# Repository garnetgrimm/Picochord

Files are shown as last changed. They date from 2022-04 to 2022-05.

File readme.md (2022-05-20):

# Picochord
An open source digital Omnichord clone based on the Raspberry Pi Pico. The firmware is currently configured to only generate audio from the input signals, but usb/analog midi support is in the works for the near future.
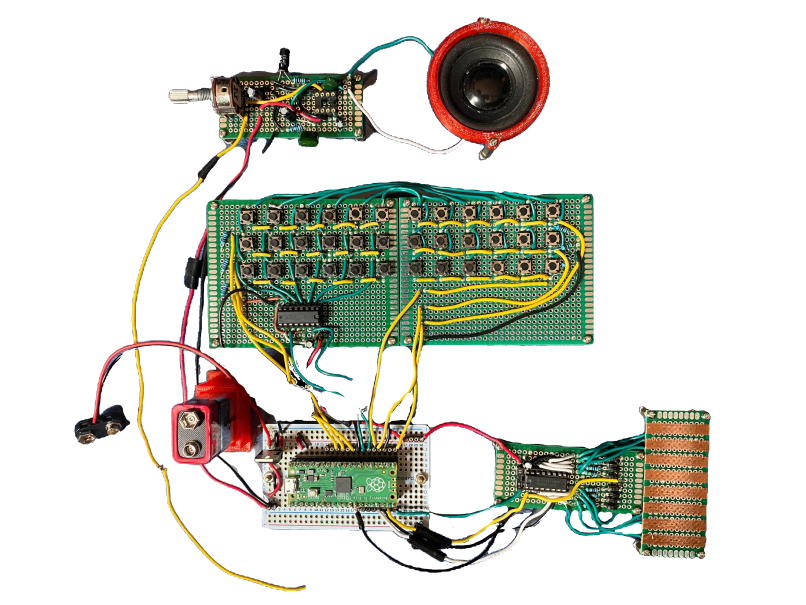
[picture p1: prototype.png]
Prototype


## Building the Firmware
The getting started guide has detailed instructions for building on each OS. https://datasheets.raspberrypi.com/pico/getting-started-with-pico.pdf

You will likely have to cd into the build directory to configure cmake and build.

## Circuits
The entire Picochord is comprised of three main subcircuits, all driven by the pico. 

* Keypad
* Strumpad
* Speaker amplifier

The PCB directory contains simulations, schematics, PCB's and screenshots for each of the circuits. The schematics/PCBs can be viewed with KiCad 6.0

## Chassis
The PCB's were screwed directly into a acrylic board. The only other required pieces were a battery holder and speaker holder which I have included STL's and FreeCad files for.

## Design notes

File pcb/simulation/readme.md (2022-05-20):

# Simulations
To view a live demo of the circuits follow these steps

* Go to https://www.falstad.com/circuit/circuitjs.html
* "Open File"
* Upload either of the .circuitjs.txt files

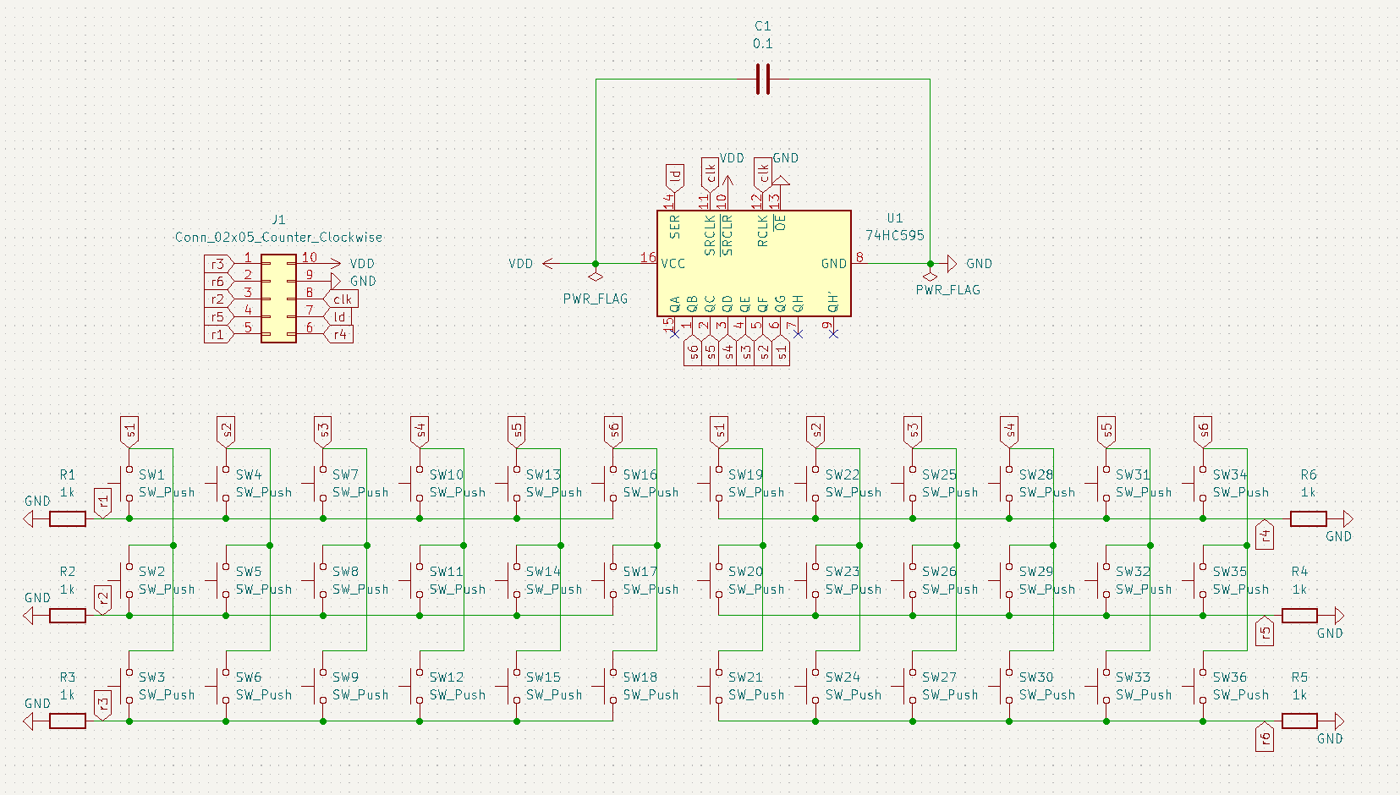
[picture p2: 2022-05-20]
pcb/image/keypad_schematic.png

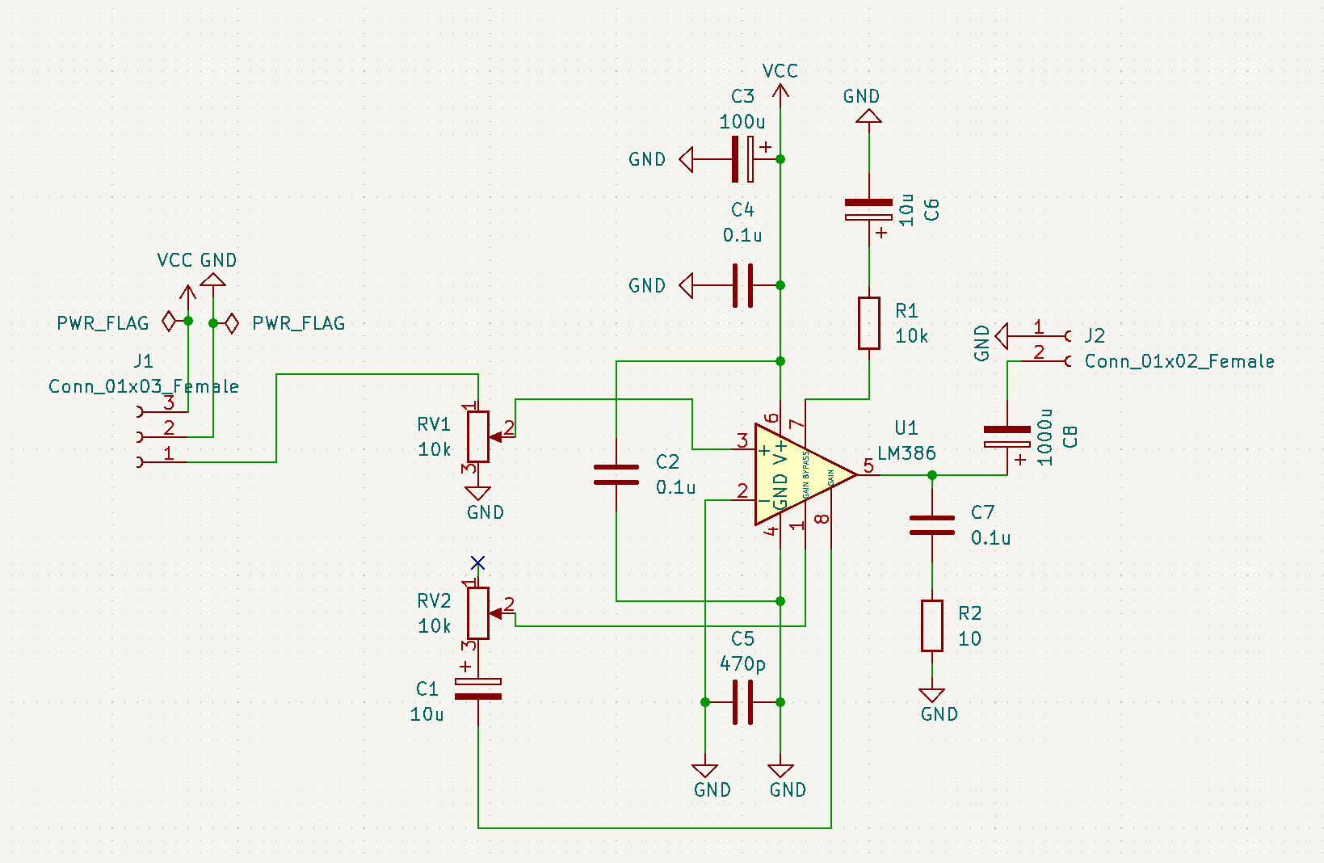
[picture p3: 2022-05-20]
pcb/image/speaker_schematic.png

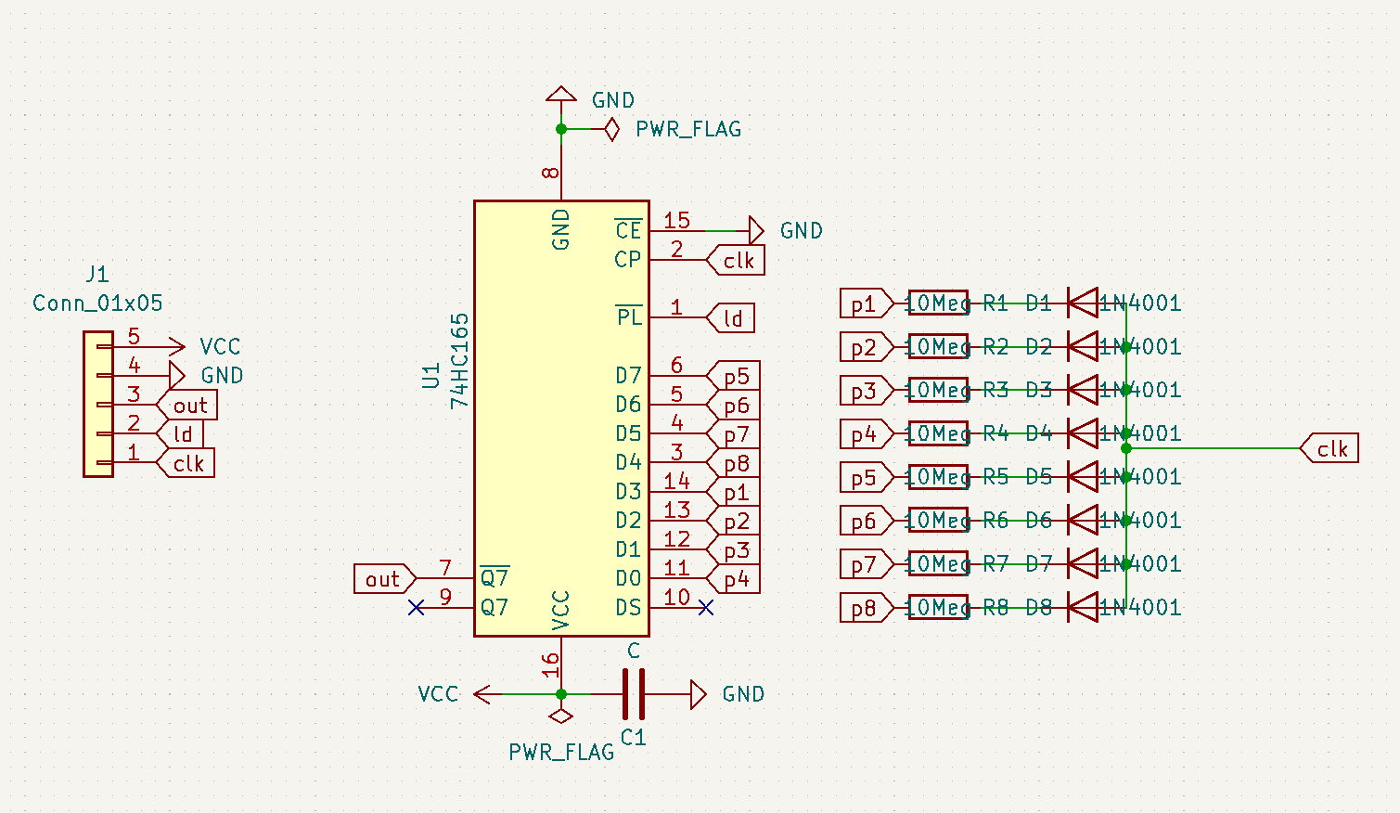
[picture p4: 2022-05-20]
pcb/image/strumpad_schematic.png

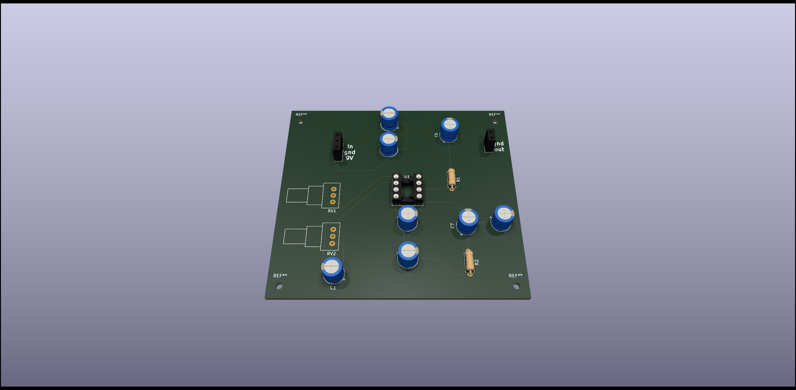
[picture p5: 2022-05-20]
pcb/image/speaker.png

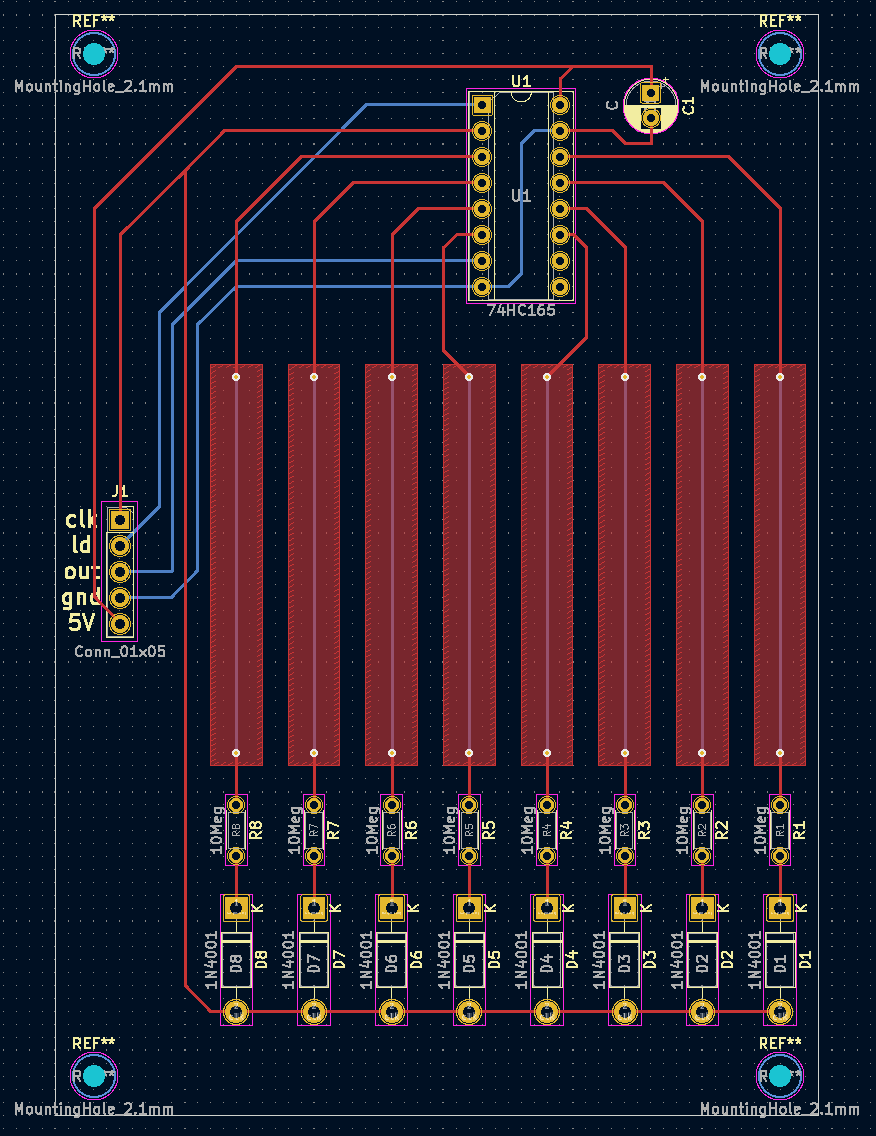
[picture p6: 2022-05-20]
pcb/image/strumpad_pcb.png

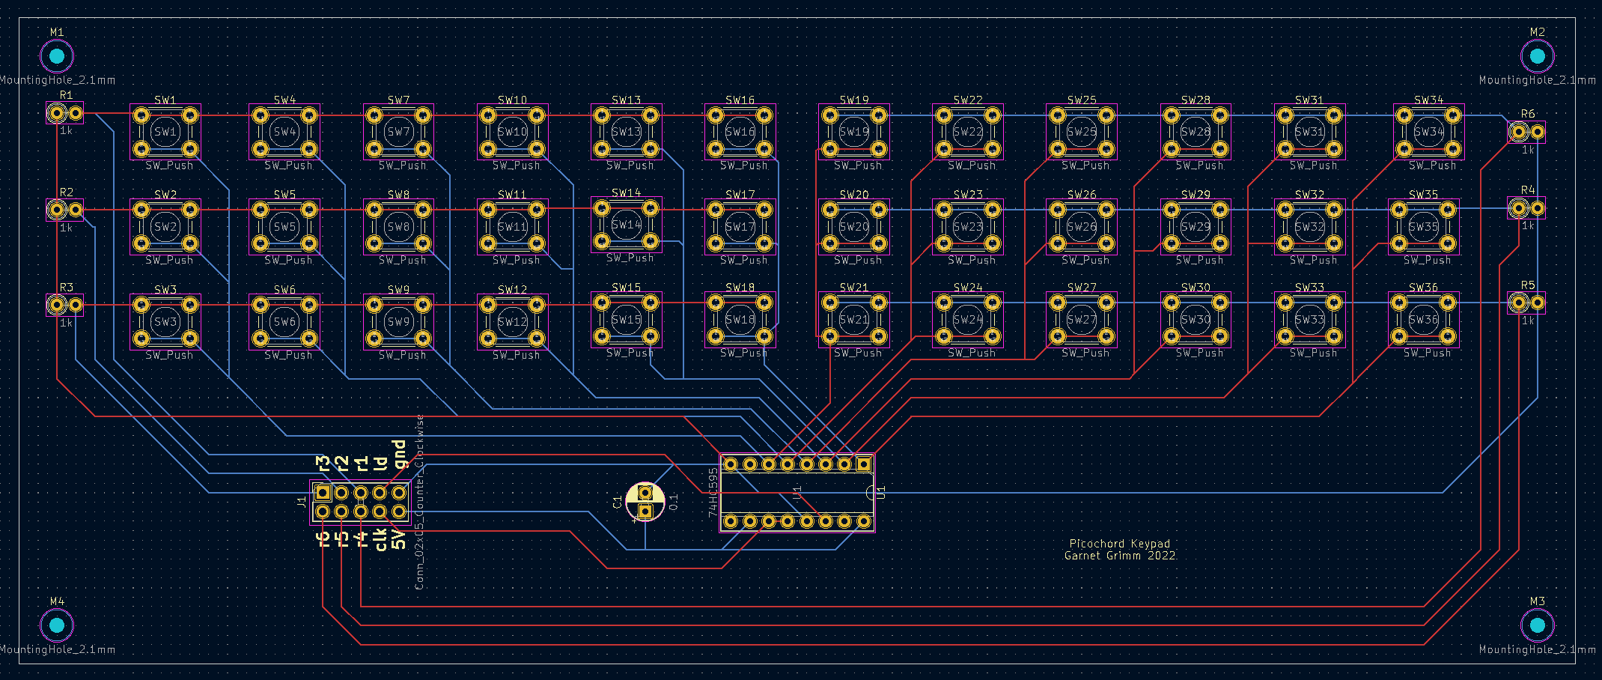
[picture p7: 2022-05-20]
pcb/image/keypad_pcb.png

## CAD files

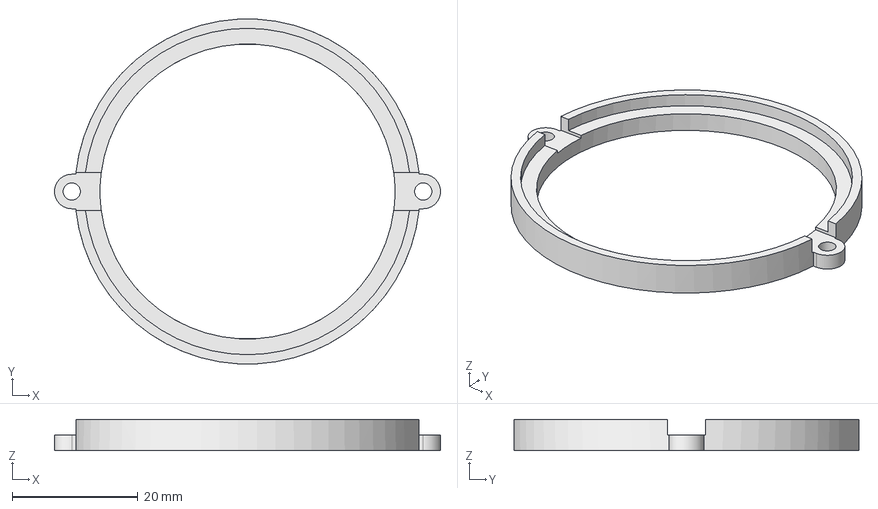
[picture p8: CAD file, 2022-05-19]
chassis/speaker_support.FCStd
61.5 x 54.9 x 5.00 mm

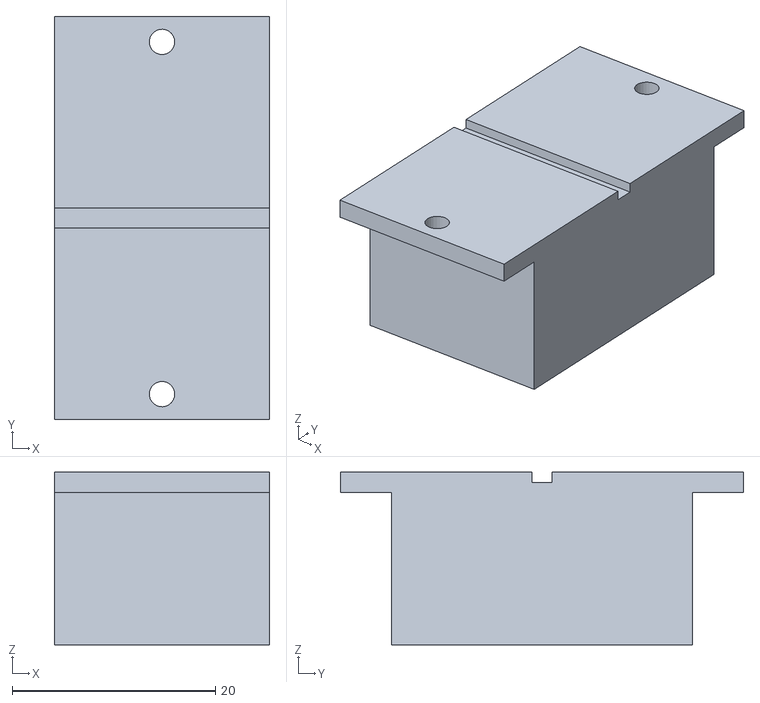
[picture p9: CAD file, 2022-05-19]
chassis/battery_support.stl
21.2 x 39.7 x 17.0

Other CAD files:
chassis/speaker_support.stl

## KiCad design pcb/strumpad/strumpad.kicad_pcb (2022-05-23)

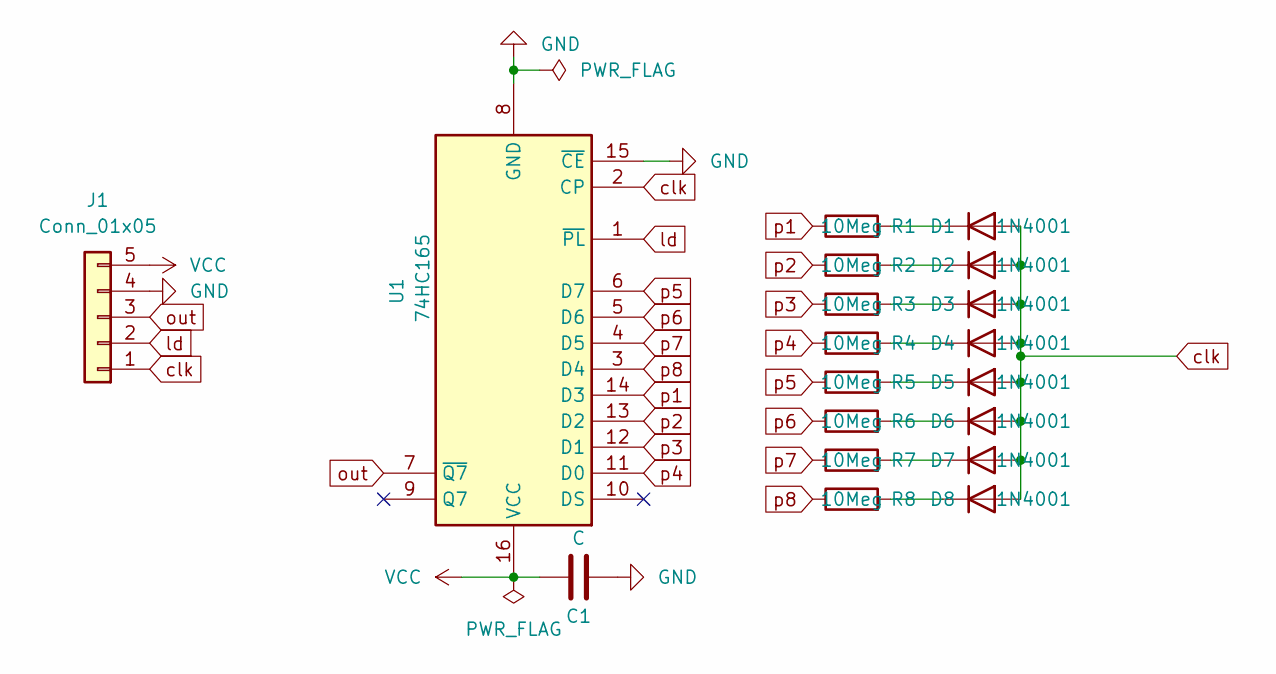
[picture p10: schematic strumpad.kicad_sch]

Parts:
C1: C; CP_Radial_D5.0mm_P2.50mm
D1, D2, D3, D4, D5, D6, D7, D8: 1N4001; D_DO-41_SOD81_P10.16mm_Horizontal
J1: Conn_01x05; PinSocket_1x05_P2.54mm_Vertical
R1, R2, R3, R4, R5, R6, R7, R8: 10Meg; R_Axial_DIN0204_L3.6mm_D1.6mm_P5.08mm_Horizontal
U1: 74HC165; DIP-16_W7.62mm_Socket

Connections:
GND: C1.2, J1.4, U1.8 (GND), U1.15 (~CE)
unnamed: D1.1 (K), R1.2
unnamed: D2.1 (K), R2.2
unnamed: D3.1 (K), R3.2
unnamed: D4.1 (K), R4.2
unnamed: D5.1 (K), R5.2
unnamed: D6.1 (K), R6.2
unnamed: D7.1 (K), R7.2
unnamed: D8.1 (K), R8.2
VCC: C1.1, J1.5, U1.16 (VCC)
clk: D1.2 (A), D2.2 (A), D3.2 (A), D4.2 (A), D5.2 (A), D6.2 (A), D7.2 (A), D8.2 (A), J1.1, U1.2 (CP)
ld: J1.2, U1.1 (~PL)
out: J1.3, U1.7 (~Q7)
p1: R1.1, U1.14 (D3)
p2: R2.1, U1.13 (D2)
p3: R3.1, U1.12 (D1)
p4: R4.1, U1.11 (D0)
p5: R5.1, U1.6 (D7)
p6: R6.1, U1.5 (D6)
p7: R7.1, U1.4 (D5)
p8: R8.1, U1.3 (D4)

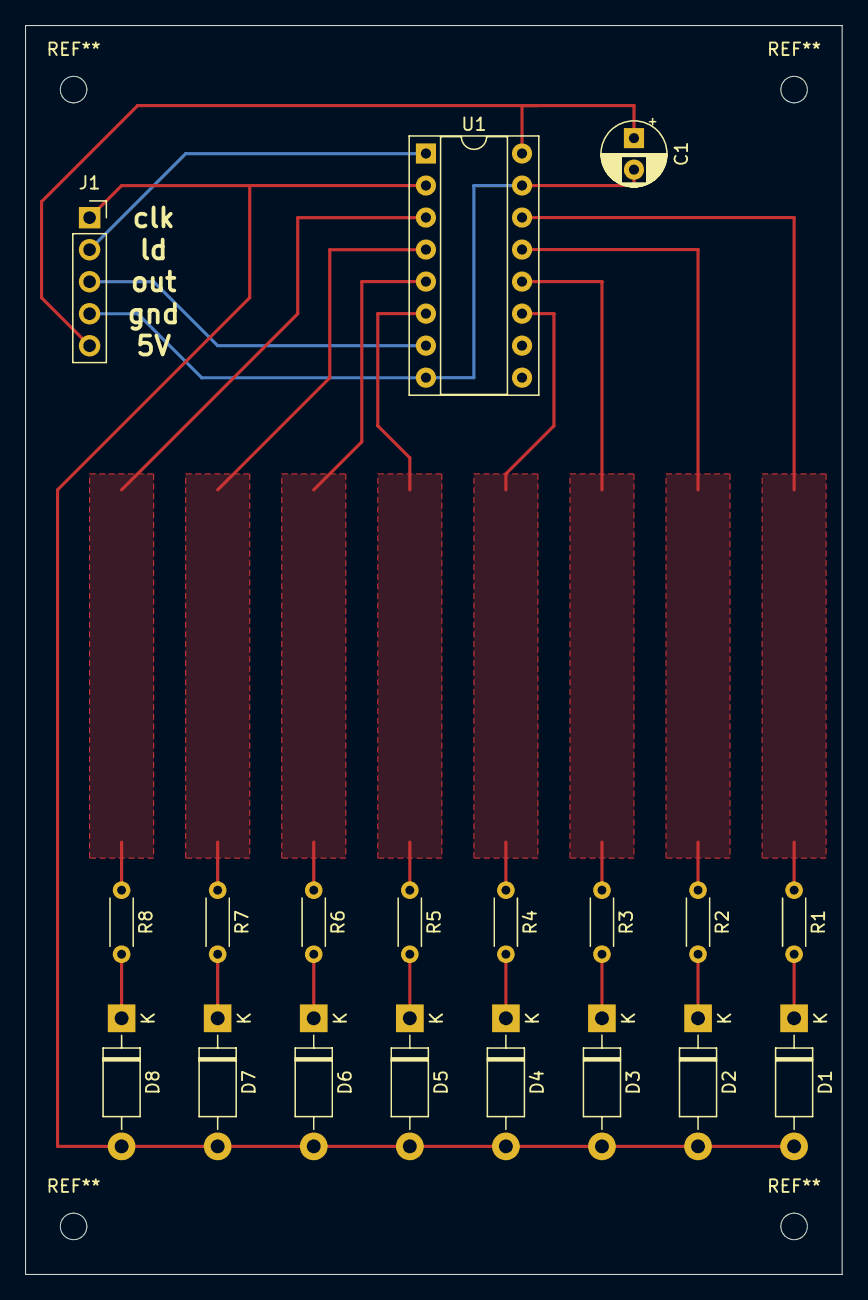
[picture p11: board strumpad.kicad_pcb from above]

Board: 2 copper layers, 64.8 x 99.1 mm, 19 parts (0 on the bottom side), 21 nets.

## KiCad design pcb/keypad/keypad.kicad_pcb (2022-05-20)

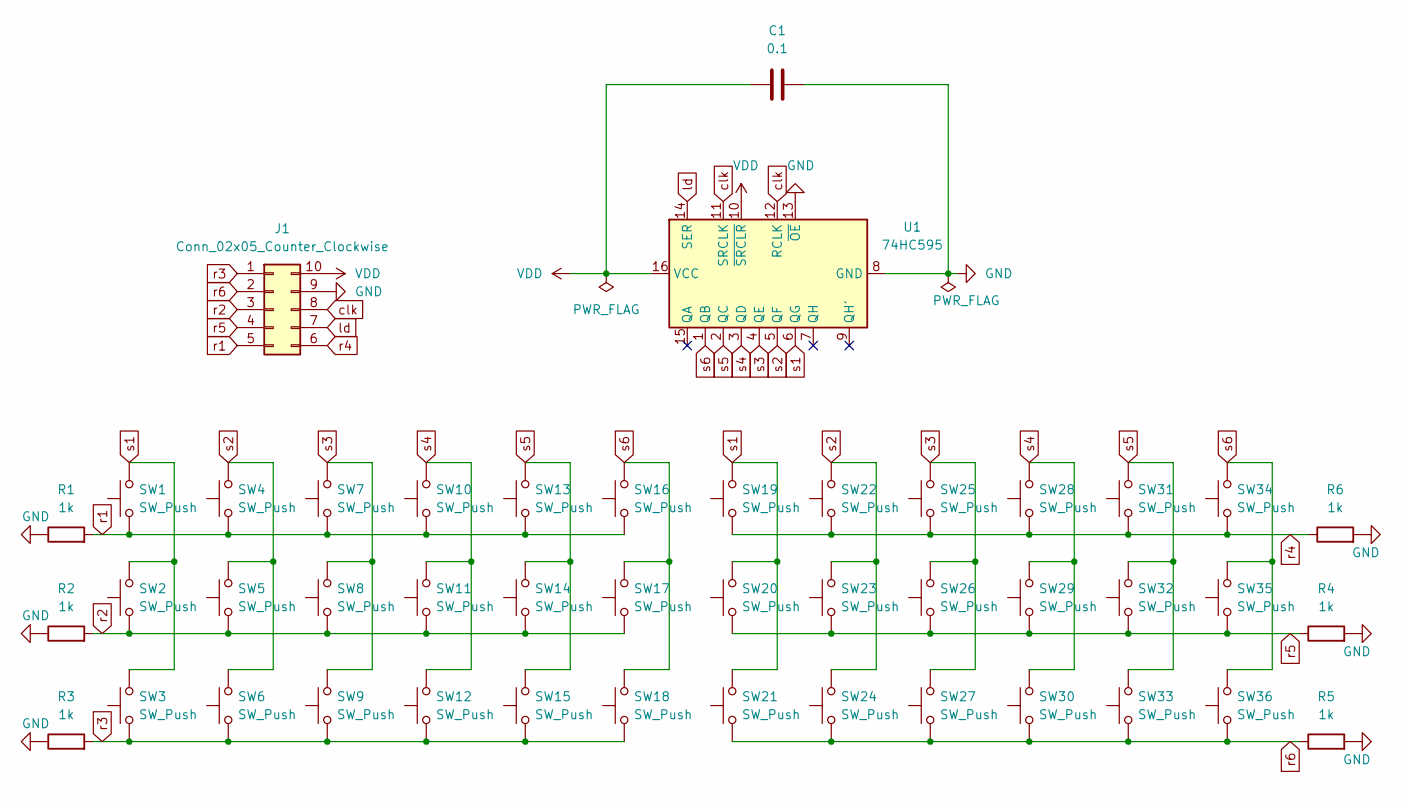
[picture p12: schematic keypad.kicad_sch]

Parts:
C1: 0.1; CP_Radial_D5.0mm_P2.50mm
J1: Conn_02x05_Counter_Clockwise; PinSocket_2x05_P2.54mm_Vertical
R1, R2, R3, R4, R5, R6: 1k; R_Axial_DIN0207_L6.3mm_D2.5mm_P2.54mm_Vertical
SW1, SW2, SW3, SW4, SW5, SW6, SW7, SW8, SW9, SW10, SW11, SW12, SW13, SW14, SW15, SW16, SW17, SW18, SW19, SW20, SW21, SW22, SW23, SW24, SW25, SW26, SW27, SW28, SW29, SW30, SW31, SW32, SW33, SW34, SW35, SW36: SW_Push; SW_PUSH_6mm
U1: 74HC595; DIP-16_W7.62mm_Socket

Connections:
GND: C1.2, J1.9, R1.1, R2.1, R3.1, R4.2, R5.2, R6.2, U1.8 (GND), U1.13 (~OE)
VDD: C1.1, J1.10, U1.10 (~SRCLR), U1.16 (VCC)
clk: J1.8, U1.11 (SRCLK), U1.12 (RCLK)
ld: J1.7, U1.14 (SER)
r1: J1.5, R1.2, SW1.1, SW4.1, SW7.1, SW10.1, SW13.1, SW16.1
r2: J1.3, R2.2, SW2.1, SW5.1, SW8.1, SW11.1, SW14.1, SW17.1
r3: J1.1, R3.2, SW3.1, SW6.1, SW9.1, SW12.1, SW15.1, SW18.1
r4: J1.6, R6.1, SW19.1, SW22.1, SW25.1, SW28.1, SW31.1, SW34.1
r5: J1.4, R4.1, SW20.1, SW23.1, SW26.1, SW29.1, SW32.1, SW35.1
r6: J1.2, R5.1, SW21.1, SW24.1, SW27.1, SW30.1, SW33.1, SW36.1
s1: SW1.2, SW2.2, SW3.2, SW19.2, SW20.2, SW21.2, U1.6 (QG)
s2: SW4.2, SW5.2, SW6.2, SW22.2, SW23.2, SW24.2, U1.5 (QF)
s3: SW7.2, SW8.2, SW9.2, SW25.2, SW26.2, SW27.2, U1.4 (QE)
s4: SW10.2, SW11.2, SW12.2, SW28.2, SW29.2, SW30.2, U1.3 (QD)
s5: SW13.2, SW14.2, SW15.2, SW31.2, SW32.2, SW33.2, U1.2 (QC)
s6: SW16.2, SW17.2, SW18.2, SW34.2, SW35.2, SW36.2, U1.1 (QB)

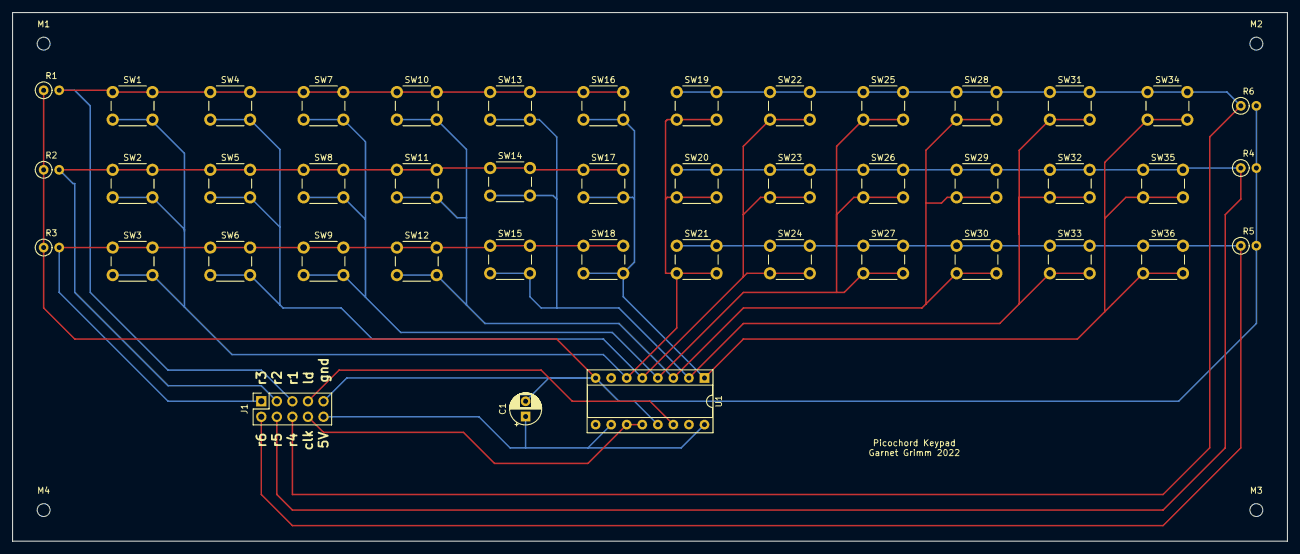
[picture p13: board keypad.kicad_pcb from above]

Board: 2 copper layers, 208.3 x 86.4 mm, 49 parts (0 on the bottom side), 16 nets.

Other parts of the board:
M1, M2, M3, M4: MountingHole_2.1mm

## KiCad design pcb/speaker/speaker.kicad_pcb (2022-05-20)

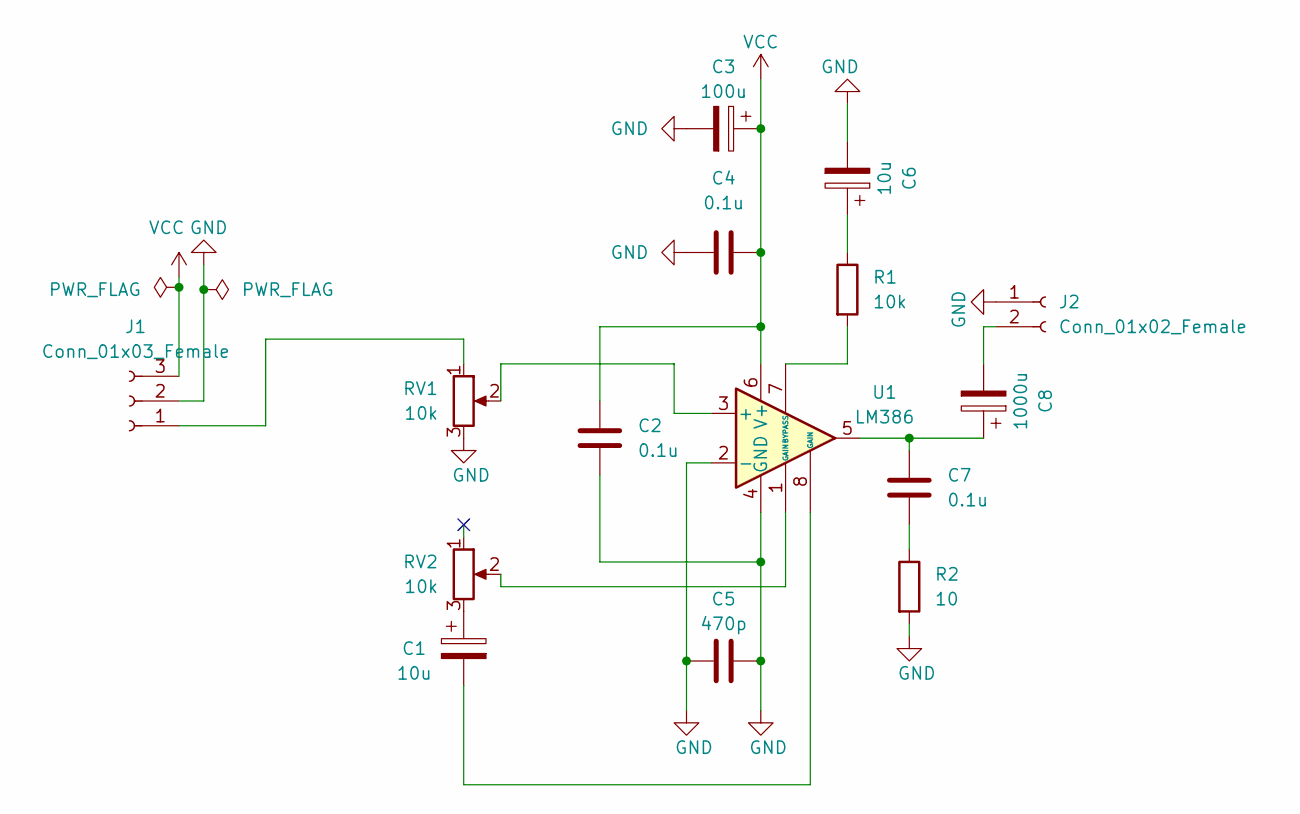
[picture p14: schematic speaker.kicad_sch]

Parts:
C1, C6: 10u; CP_Radial_D6.3mm_P2.50mm
C2, C4, C7: 0.1u; CP_Radial_D6.3mm_P2.50mm
C3: 100u; CP_Radial_D6.3mm_P2.50mm
C5: 470p; CP_Radial_D6.3mm_P2.50mm
C8: 1000u; CP_Radial_D6.3mm_P2.50mm
J1: Conn_01x03_Female; PinSocket_1x03_P2.54mm_Vertical
J2: Conn_01x02_Female; PinSocket_1x02_P2.54mm_Vertical
R1: 10k; R_Axial_DIN0207_L6.3mm_D2.5mm_P7.62mm_Horizontal
R2: 10; R_Axial_DIN0207_L6.3mm_D2.5mm_P7.62mm_Horizontal
RV1, RV2: 10k; Potentiometer_Alps_RK09Y11_Single_Horizontal
U1: LM386; DIP-8_W7.62mm_Socket

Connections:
GND: C2.1, C3.2, C4.1, C5.1, C5.2, C6.2, J1.2, J2.1, R2.2, RV1.3, U1.2 (-), U1.4 (GND)
unnamed: C1.1, RV2.3
unnamed: C1.2, U1.8 (GAIN)
unnamed: C6.1, R1.1
unnamed: C7.1, R2.1
unnamed: C7.2, C8.1, U1.5
unnamed: C8.2, J2.2
unnamed: R1.2, U1.7 (BYPASS)
unnamed: J1.1, RV1.1
unnamed: RV1.2, U1.3 (+)
unnamed: RV2.2, U1.1 (GAIN)
VCC: C2.2, C3.1, C4.2, J1.3, U1.6 (V+)

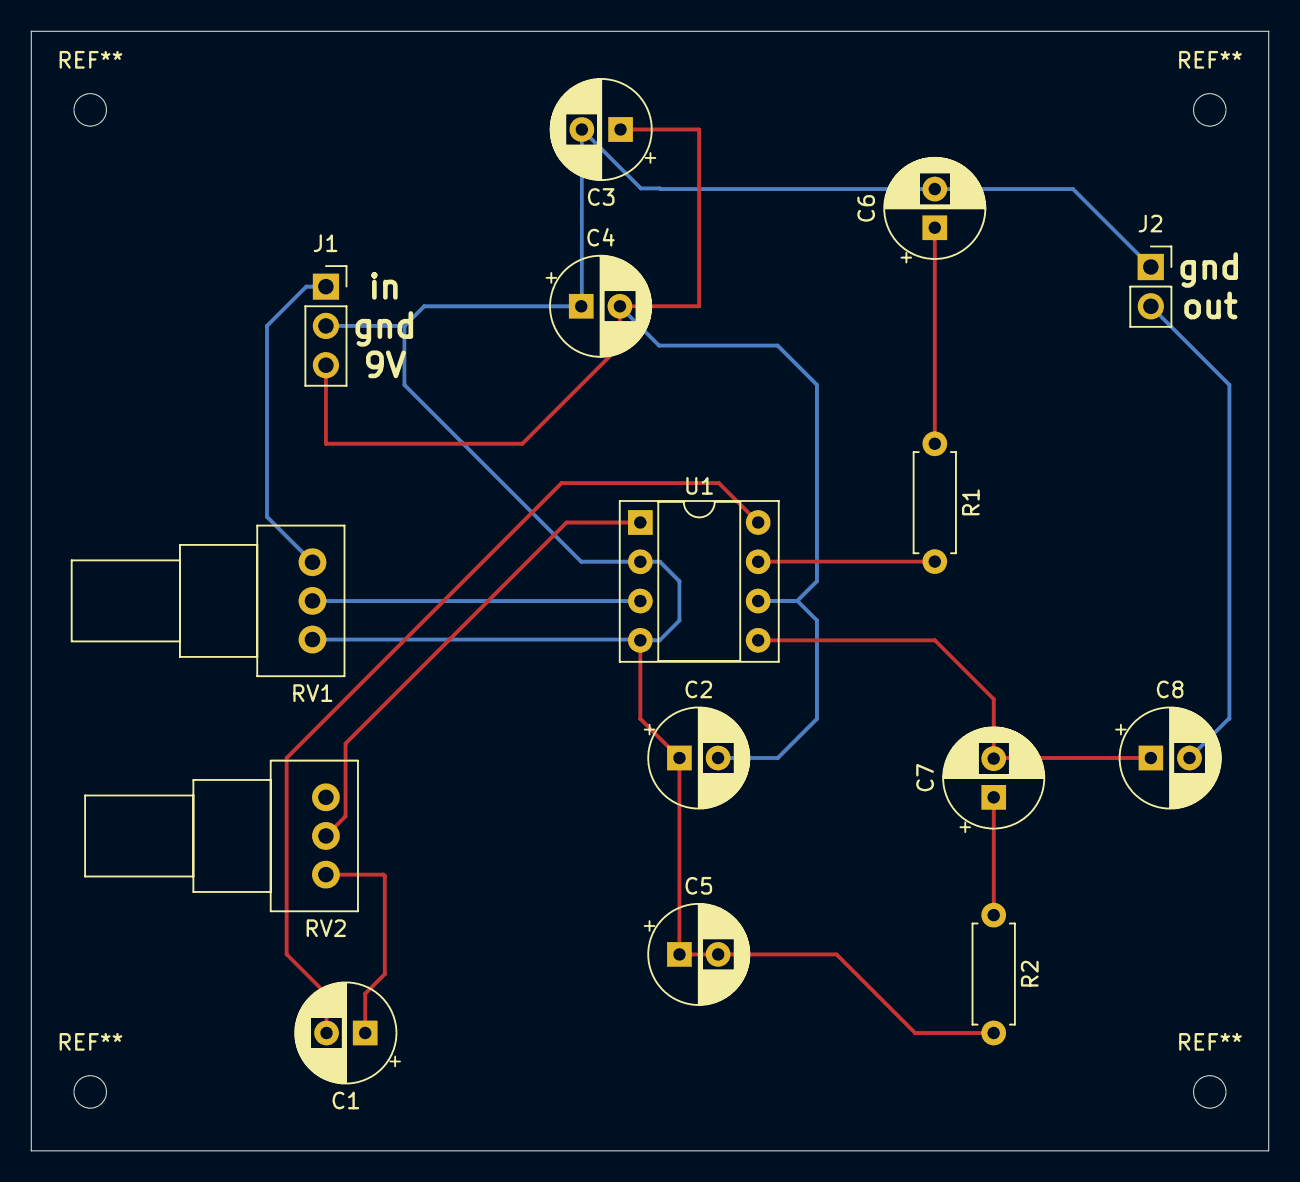
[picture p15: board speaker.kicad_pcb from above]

Board: 2 copper layers, 80.0 x 72.4 mm, 15 parts (0 on the bottom side), 12 nets.

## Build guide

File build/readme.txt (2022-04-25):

Steps to build

Developer Command Prompt for VS
cd build
cmake -G "NMake Makefiles" ..
nmake

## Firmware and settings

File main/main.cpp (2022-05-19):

#include <stdio.h>
#include <math.h>
#include "pico/stdlib.h"
#include "hardware/gpio.h"
#include "hardware/clocks.h"
#include "hardware/pwm.h"
#include "hardware/adc.h"
#include "hardware/irq.h"  // interrupts
#include "hardware/sync.h" // wait for interrupt 
 
// Audio PIN is to match some of the design guide shields. 
#define OSCILLATORS 16

#include "chord.h"
#include "keypad.h"
#include "oscillator.h"
#include "strumpad.h"

const uint8_t audioPin = 10;
const uint8_t sLOADPin = 15;  //strumpad load pin
const uint8_t sCLKPin = 14;	 //strumpad clock pin
const uint8_t sINPin = 13;	 //strumpad input pin
//use some of the previously skipped pins. They're ok to use, the associated timer is just being utilized.
const uint8_t kLOADPin = 20; //keypad load pin
const uint8_t kCLKPin = 21;	 //keypad clock pin
const uint8_t kR1Pin = 27;	 //keypad row one pin
const uint8_t kR2Pin = 26;	 //keypad row two pin
const uint8_t kR3Pin = 22;	 //keypad row three pin
const uint8_t kR4Pin = 16;	 //keypad row one pin
const uint8_t kR5Pin = 18;	 //keypad row two pin
const uint8_t kR6Pin = 19;	 //keypad row three pin

uint8_t current_col = 0;
uint8_t current_pad = 0;

const float keypadLoadHz = 60.0f;
const float keypadClockHz = keypadClockHz * (float)cols;
const float strumLoadHz = 500.0f;

SquareWave wave;
Oscillator oscs[OSCILLATORS];

Chord chord = NoChord();

Keypad activePad;
Keypad finalPad;

Strumpad strumPad;

uint8_t level = 0;

bool mute_chord = true;

uint32_t strum_load_cnt = 0;
uint32_t strum_load_max = 15;
uint32_t strum_tick_time = 250;

bool blinky = false;

float midiFreq(int midiNum) {
	return 440.0f*powf(2.0f, ((float)midiNum - 69.0f) / 12.0f);
}

void pwm_interrupt_handler() {
    pwm_clear_irq(pwm_gpio_to_slice_num(audioPin));
    pwm_set_gpio_level(audioPin, level);
}

bool tick_oscillators(struct repeating_timer *t) {
	sink sum { 0.0f };
	if(!mute_chord) {
		for(int i = 0; i < 3; i++) {	
			sum += oscs[i].tick(false);
		}
	}
	for(int i = 3; i < 11; i++) {	
		sum += oscs[i].tick(true);
	}
	level = static_cast<int8_t>((20)*sum) + 0x7F;
	return true;
}

void set_chord(Chord c) {
	chord = c;
	if(chord.type == BLANK) {
		mute_chord = true;
		for(int i = 0; i < 3; i++) {
			oscs[i].set_freq(440);
		}
	} else {
		mute_chord = false;
		for(int i = 0; i < 3; i++) {
			float freq = midiFreq(chord[i % 3]);
			oscs[i].set_freq(freq);
		}
		for(int i = 3; i < OSCILLATORS; i++) {
			float freq = midiFreq(chord[i % 3]);
			int fscale = 1<<((i-3)/3);
			oscs[i].set_freq(freq*(float)fscale);
		}
	}
}

void tick_strumpad(void) {
	if(strum_load_cnt == 10) {
		gpio_put(sLOADPin, false);
		gpio_put(sCLKPin, false);
		gpio_put(sLOADPin, true);
	}
	
	if(strum_load_cnt < strum_load_max)  {
		strum_load_cnt++;
		return;
	}
	
	if(!gpio_get_out_level(sCLKPin)) {
		
		bool pad_on = gpio_get(sINPin) && (current_pad == 7);
		strumPad.set_strumpad(current_pad, pad_on);
		if(pad_on) {
			oscs[current_pad + 3].volume = sink(1.0f);
		}
		
		current_pad++;
		if(current_pad > 8) {
			current_pad = 0;
			gpio_put(sCLKPin, true);
			strum_load_cnt = 0;
			return;
		} else {
			gpio_put(sCLKPin, true);
		}
	} else {
		gpio_put(sCLKPin, false);
	}
}

void tick_keypad(void) {
	bool clkStat = gpio_get_out_level(kCLKPin);	
	
	if(clkStat) {
		activePad.set_keypad(0, 5 - (current_col - 2), gpio_get(kR1Pin));
		activePad.set_keypad(1, 5 - (current_col - 2), gpio_get(kR2Pin));
		activePad.set_keypad(2, 5 - (current_col - 2), gpio_get(kR3Pin));
		activePad.set_keypad(0, current_col - 2 + 6, gpio_get(kR4Pin));
		activePad.set_keypad(1, current_col - 2 + 6, gpio_get(kR5Pin));
		activePad.set_keypad(2, current_col - 2 + 6, gpio_get(kR6Pin));
		current_col++;
		
		gpio_put(kLOADPin, false);
	}
	
	gpio_put(kCLKPin, !clkStat);
	
	if(current_col >= cols) {
		current_col = 0;
		gpio_put(kLOADPin, true);
		
		finalPad.update(activePad);	
		
		Chord detChord = finalPad.to_chord();		
		if(detChord.type != chord.type || detChord.root != chord.root) {
			set_chord(detChord);
		};
	}
}

bool input_ISR(struct repeating_timer *t) {
	tick_keypad();
	tick_strumpad();
	return true;
}

int main(void) {
	
    stdio_init_all();
	set_chord(MajChord(noteMap[0]));
	
	const uint LED_PIN = PICO_DEFAULT_LED_PIN;
    gpio_init(LED_PIN);
    gpio_set_dir(LED_PIN, GPIO_OUT);
	
	//strumpad control signals
	gpio_init(sLOADPin);
	gpio_init(sCLKPin);
	gpio_init(sINPin);

	gpio_set_dir(sLOADPin, GPIO_OUT);
	gpio_set_dir(sCLKPin, GPIO_OUT);
	gpio_set_dir(sINPin, GPIO_IN);
	
	//keypad control signals
	gpio_init(kLOADPin);
	gpio_init(kCLKPin);
	gpio_init(kR1Pin);
	gpio_init(kR2Pin);
	gpio_init(kR3Pin);
	gpio_init(kR4Pin);
	gpio_init(kR5Pin);
	gpio_init(kR6Pin);
	
    gpio_set_dir(kLOADPin, GPIO_OUT);
	gpio_set_dir(kCLKPin,  GPIO_OUT);
	gpio_set_dir(kR1Pin,   GPIO_IN);
	gpio_set_dir(kR2Pin,   GPIO_IN);
	gpio_set_dir(kR3Pin,   GPIO_IN);	
	gpio_set_dir(kR4Pin,   GPIO_IN);
	gpio_set_dir(kR5Pin,   GPIO_IN);
	gpio_set_dir(kR6Pin,   GPIO_IN);	

    set_sys_clock_khz(176000, true); 
    gpio_set_function(audioPin, GPIO_FUNC_PWM);

    int audio_pin_slice = pwm_gpio_to_slice_num(audioPin);

    // Setup PWM interrupt to fire when PWM cycle is complete
    pwm_clear_irq(audio_pin_slice);
    pwm_set_irq_enabled(audio_pin_slice, true);
    // set the handle function above
    irq_set_exclusive_handler(PWM_IRQ_WRAP, pwm_interrupt_handler); 
    irq_set_enabled(PWM_IRQ_WRAP, true);

    // Setup PWM for audio output
    pwm_config config = pwm_get_default_config();
    //Base clock 176,000,000 Hz divide by wrap 250 then the clock divider further divides
    //to set the interrupt rate. 
    //11 KHz is fine for speech. Phone lines generally sample at 8 KHz
    //So clkdiv should be as follows for given sample rate
	//16.0 for 5.5kHz
	//8.0f for 11 KHz
    //4.0f for 22 KHz
    //2.0f for 44 KHz etc
    pwm_config_set_clkdiv(&config, 8.0f); 
    pwm_config_set_wrap(&config, 275); 
    pwm_init(audio_pin_slice, &config, true);

    pwm_set_gpio_level(audioPin, 0);
	
	for(int i = 0; i < OSCILLATORS; i++) {
		oscs[i].set_wave(&wave);
		oscs[i].volume = sink(0.0f);
	}
	
	struct repeating_timer tim1;
	add_repeating_timer_us(-static_cast<int32_t>(SAMPLE_PERIOD_MICRO), tick_oscillators, NULL, &tim1);
	
	struct repeating_timer tim2;
	add_repeating_timer_us(strum_tick_time, input_ISR, NULL, &tim2);
	
	Chord dummyChord[4];
	int dummyStrumProg[13] = { 4, 11, 2, 7, 3, 0, 10, 5, 8, 9, 12, 6, 1 };
		
	dummyChord[0] = Chord::makeChord(60, MAJOR);
	dummyChord[1] = Chord::makeChord(64, MINOR);
	dummyChord[2] = Chord::makeChord(65, MAJOR);
	dummyChord[3] = Chord::makeChord(62, MINOR);
	
	oscs[0].volume = sink(0.5f);
	oscs[1].volume = sink(0.5f);
	oscs[2].volume = sink(0.5f);
	
	mute_chord = false;
	
	while(1) {
		printf("\033[2J");
		finalPad.print();
		strumPad.print();
		//blinky = !blinky;
		//gpio_put(LED_PIN, blinky);
		sleep_ms(100);
		/*
		for(int i = 0; i < 13; i++) {
			int strumPad = dummyStrumProg[i]+3;
			oscs[strumPad].volume = sink(1.0f);
			
			printf("\033[2J");	
			printf("%d %d\r\n", chord.root, chord.type);
			finalPad.print();
			
			sleep_ms(500);
		}
		*/
	}
	
}

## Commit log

2022-04-26 got some button functionality
2022-04-29 minor bug fixes and print statements!
    [main.cpp]
2022-04-30 keypad routine switched from pwm based to timer based. Fixes a couple bugs and makes control logic easier
    [main.cpp]
2022-05-03 decided to just emulate all the individual oscillators sorrynotsorry
    [main.cpp]
2022-05-04 seperated oscillators from PWM and solved MAJOR ram issue
    [main.cpp]
2022-05-19 support for 12 columns and start to fix strum problem
    [main.cpp]
2022-05-19 some physical comonents
    [Omni.kicad_pcb, Omni.kicad_sch, battery_support.stl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]
2022-05-20 modeled PCB
    [keypad.kicad_pcb, keypad.kicad_sch, strumpad.kicad_pcb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]
2022-05-20 annotated pinout
    [keypad.kicad_pcb, speaker.kicad_pcb, strumpad.kicad_pcb]
2022-05-23 strumpad update'
    [strumpad.kicad_pcb]
